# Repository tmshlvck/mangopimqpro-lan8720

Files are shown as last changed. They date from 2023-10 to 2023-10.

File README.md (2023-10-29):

LAN8720 board for MangoPi MQ-Pro
================================

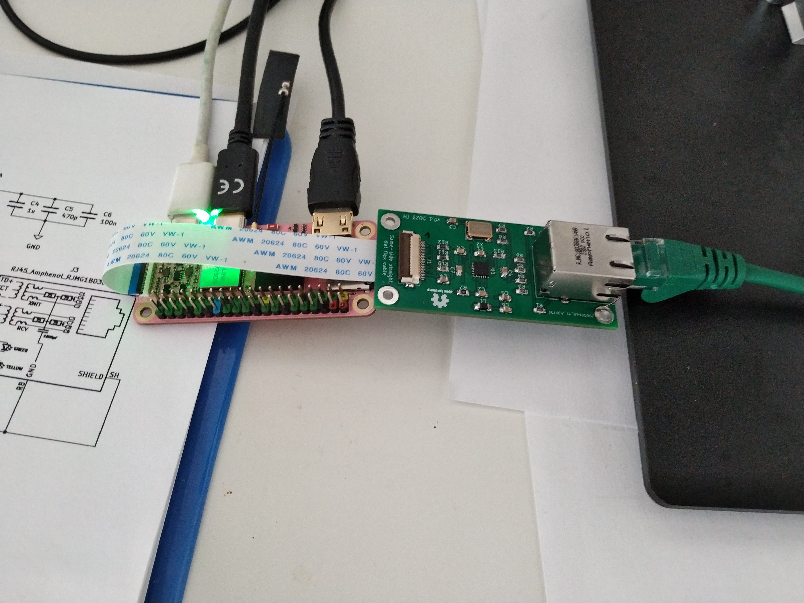
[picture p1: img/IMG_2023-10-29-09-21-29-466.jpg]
Board picture


The schematic and PCB are in HW section. Feel free to make it, it is quite cool add-on board.
Schematic: [PDF](hw/meta/schematic.pdf)

I run it with the Nezha Ubuntu image with the patch applied using this:

* clone Linux kernel tree (`git clone https://github.com/torvalds/linux.git`)
* apply the patch from this repo (`git am 0001-Add-LAN8720a-PHY-to-MangoPI-MQ-Pro-board.patch`)
* build DTB `ARCH=riscv make dtbs`
* scp the result `arch/riscv/boot/dts/allwinner/sun20i-d1-mangopi-mq-pro-lan8720.dtb` to `/boot` on MangoPi MQ-Pro
* link the current kernel DTB to this file (in my case `cd boot; rm dtb-6.2.0-35-generic; ln -s sun20i-d1-mangopi-mq-pro-lan8720.dtb dtb-6.2.0-35-generic`)
* reboot the MangoPi MQ-Pro

License
-------

HW: The TAPR Open Hardware License Version 1.0
SW: GNU GPLv3

Expected dmesg output
---------------------

```
[  104.125393] dwmac-sun8i 4500000.ethernet: IRQ eth_wake_irq not found
[  104.125445] dwmac-sun8i 4500000.ethernet: IRQ eth_lpi not found
[  104.126653] dwmac-sun8i 4500000.ethernet: PTP uses main clock
[  104.126754] dwmac-sun8i 4500000.ethernet: Current syscon value is not the default 50006 (expect 0)
[  104.140716] dwmac-sun8i 4500000.ethernet: No HW DMA feature register supported
[  104.140764] dwmac-sun8i 4500000.ethernet: RX Checksum Offload Engine supported
[  104.140794] dwmac-sun8i 4500000.ethernet: COE Type 2
[  104.140826] dwmac-sun8i 4500000.ethernet: TX Checksum insertion supported
[  104.140857] dwmac-sun8i 4500000.ethernet: Normal descriptors
[  104.140885] dwmac-sun8i 4500000.ethernet: Chain mode enabled
[  108.505636] dwmac-sun8i 4500000.ethernet end0: renamed from eth0
[  111.253079] dwmac-sun8i 4500000.ethernet end0: PHY [stmmac-0:01] driver [SMSC LAN8710/LAN8720] (irq=POLL)
[  111.260378] dwmac-sun8i 4500000.ethernet end0: Register MEM_TYPE_PAGE_POOL RxQ-0
[  111.264987] dwmac-sun8i 4500000.ethernet end0: No Safety Features support found
[  111.265046] dwmac-sun8i 4500000.ethernet end0: No MAC Management Counters available
[  111.265085] dwmac-sun8i 4500000.ethernet end0: PTP not supported by HW
[  111.282125] dwmac-sun8i 4500000.ethernet end0: configuring for phy/rmii link mode
[  287.401778] dwmac-sun8i 4500000.ethernet end0: Link is Up - 100Mbps/Full - flow control rx/tx
```

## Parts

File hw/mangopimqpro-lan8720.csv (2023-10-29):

Source: | /home/th/wip/mangopimqpro-lan8720/hw/mangopimqpro-lan8720.kicad_sch
Date: | Mon 31 Jul 2023 01:39:57 PM CEST
Tool: | Eeschema 7.0.6-1.fc38
Generator: | /usr/share/kicad/plugins/bom_csv_grouped_by_value.py
Component Count: | 28
Collated Components:
Item | Qty | Reference(s) | Value | LibPart | Footprint | Datasheet | DNP | PN
1 | 6 | C1, C2, C3, C6, C7, C8 | 100n | Device:C | Capacitor_SMD:C_0805_2012Metric_Pad1.18x1.45mm_HandSolder | ~ |  | CL21B104MACNNNC
2 | 2 | C4, C9 | 1u | Device:C | Capacitor_SMD:C_0805_2012Metric_Pad1.18x1.45mm_HandSolder | ~ |  | CL21B105KOFNNNG
3 | 1 | C5 | 470p | Device:C | Capacitor_SMD:C_0805_2012Metric_Pad1.18x1.45mm_HandSolder | ~ |  | CL21B471KBANFNC
4 | 2 | J1, J2 | Conn_01x25_Socket | Connector:Conn_01x25_Socket | Connector_FFC-FPC:Hirose_FH12-24S-0.5SH_1x24-1MP_P0.50mm_Horizontal | ~ |  | FH12-24S-0.5SH(55)
5 | 1 | J3 | RJ45_Amphenol_RJMG1BD3B8K1ANR | Connector:RJ45_Amphenol_RJMG1BD3B8K1ANR | Connector_RJ:RJ45_Amphenol_RJMG1BD3B8K1ANR | https://www.amphenol-cs.com/media/wysiwyg/files/drawing/rjmg1bd3b8k1anr.pdf |  | RJMG1BD3B8K1ANR
6 | 1 | L1 | 1uH | Device:L | Inductor_SMD:L_1206_3216Metric_Pad1.22x1.90mm_HandSolder | ~ |  | MCQ1V3216-1R0-R
7 | 2 | R1, R2 | 330 | Device:R | Resistor_SMD:R_0805_2012Metric_Pad1.20x1.40mm_HandSolder | ~ |  | RMCF0805JT330R
8 | 7 | R3, R4, R5, R6, R8, R9, R10 | 50 | Device:R | Resistor_SMD:R_0805_2012Metric_Pad1.20x1.40mm_HandSolder | ~ |  | RMCF0805JT51R0
9 | 3 | R7, R11, R12 | 5k | Device:R | Resistor_SMD:R_0805_2012Metric_Pad1.20x1.40mm_HandSolder | ~ |  | CRCW08055K00JNTA
10 | 1 | R13 | 12k1 | Device:R | Resistor_SMD:R_0805_2012Metric_Pad1.20x1.40mm_HandSolder | ~ |  | RMCF0805FG12K1
11 | 1 | U1 | LAN8720A | Interface_Ethernet:LAN8720A | Package_DFN_QFN:VQFN-24-1EP_4x4mm_P0.5mm_EP2.5x2.5mm_ThermalVias | http://ww1.microchip.com/downloads/en/DeviceDoc/8720a.pdf |  | LAN8720A-CP-ABC
12 | 1 | X2 | SG-7050CAN | Oscillator:SG-7050CAN | Oscillator:Oscillator_SMD_SeikoEpson_SG8002CA-4Pin_7.0x5.0mm | https://support.epson.biz/td/api/doc_check.php?dl=brief_SG7050CAN&lang=en |  | SG7050CAN 50.000000M-TJGA0

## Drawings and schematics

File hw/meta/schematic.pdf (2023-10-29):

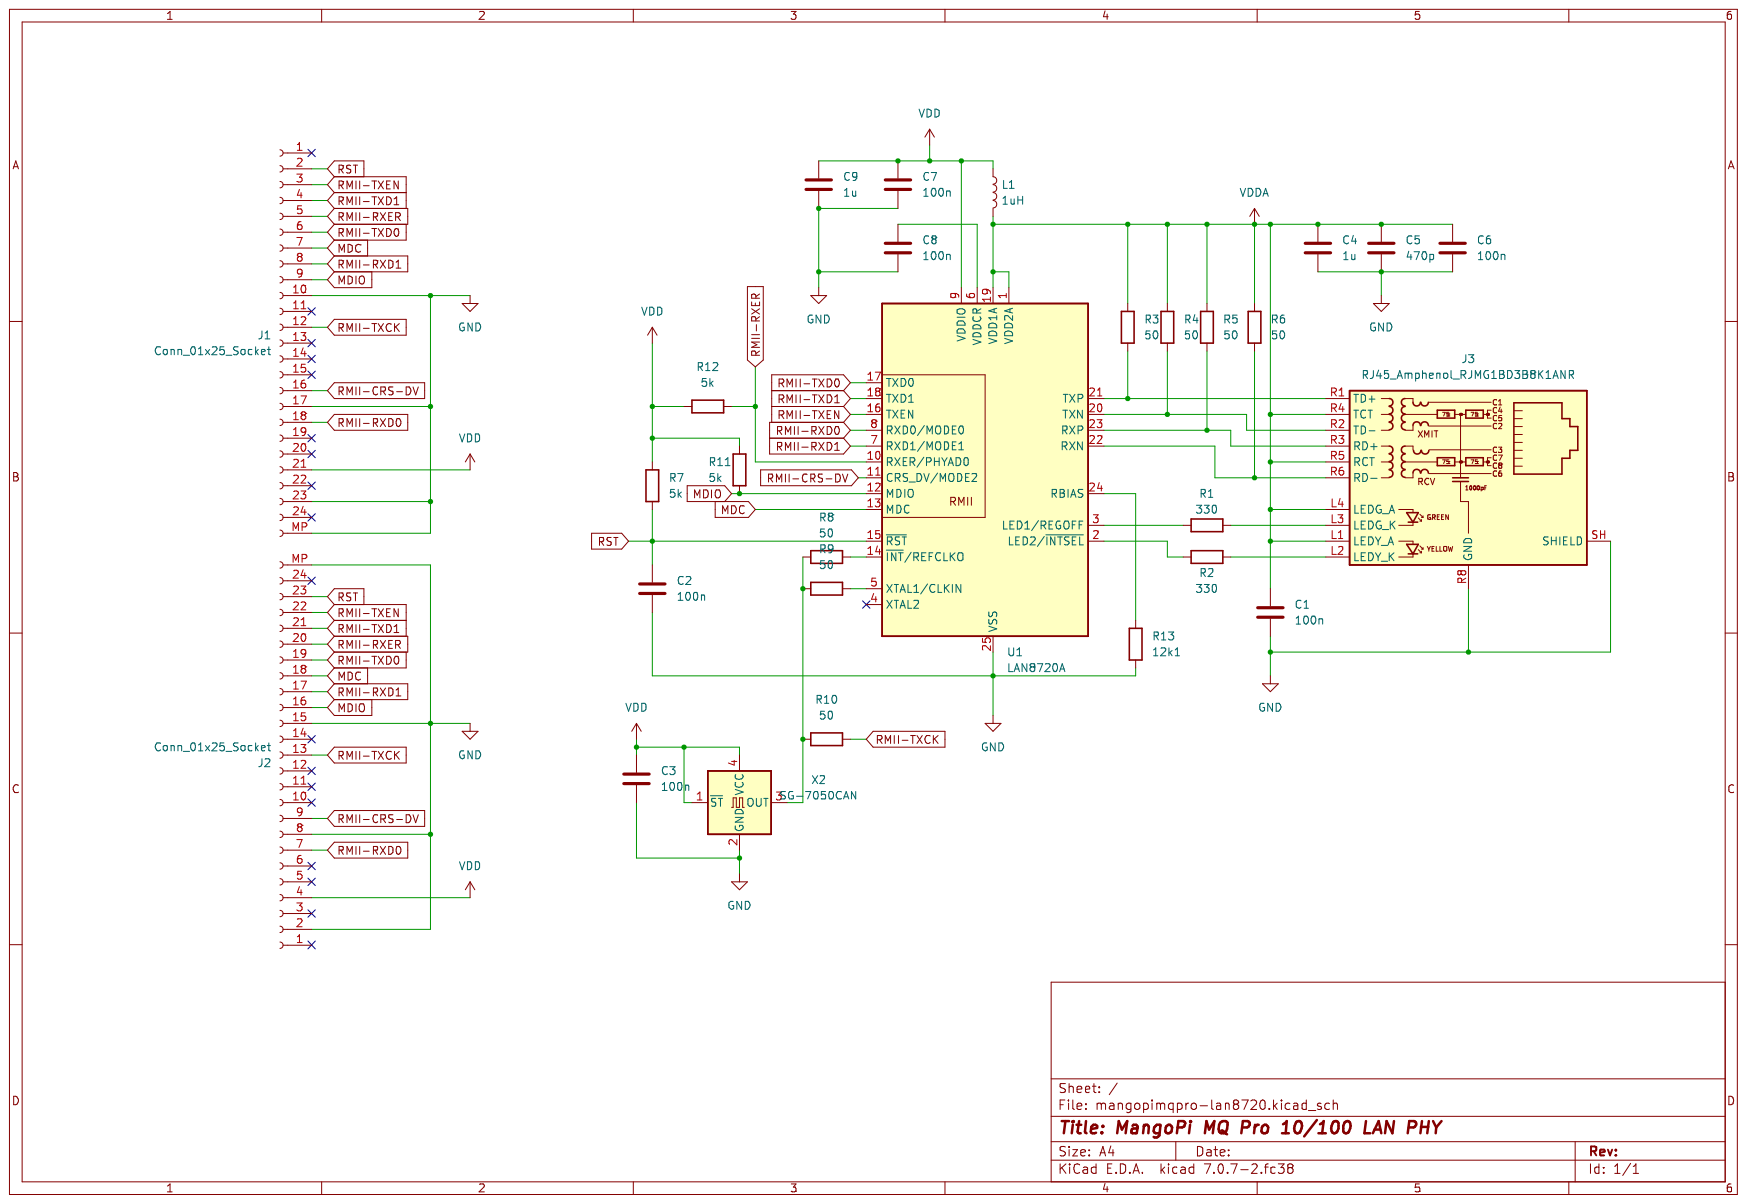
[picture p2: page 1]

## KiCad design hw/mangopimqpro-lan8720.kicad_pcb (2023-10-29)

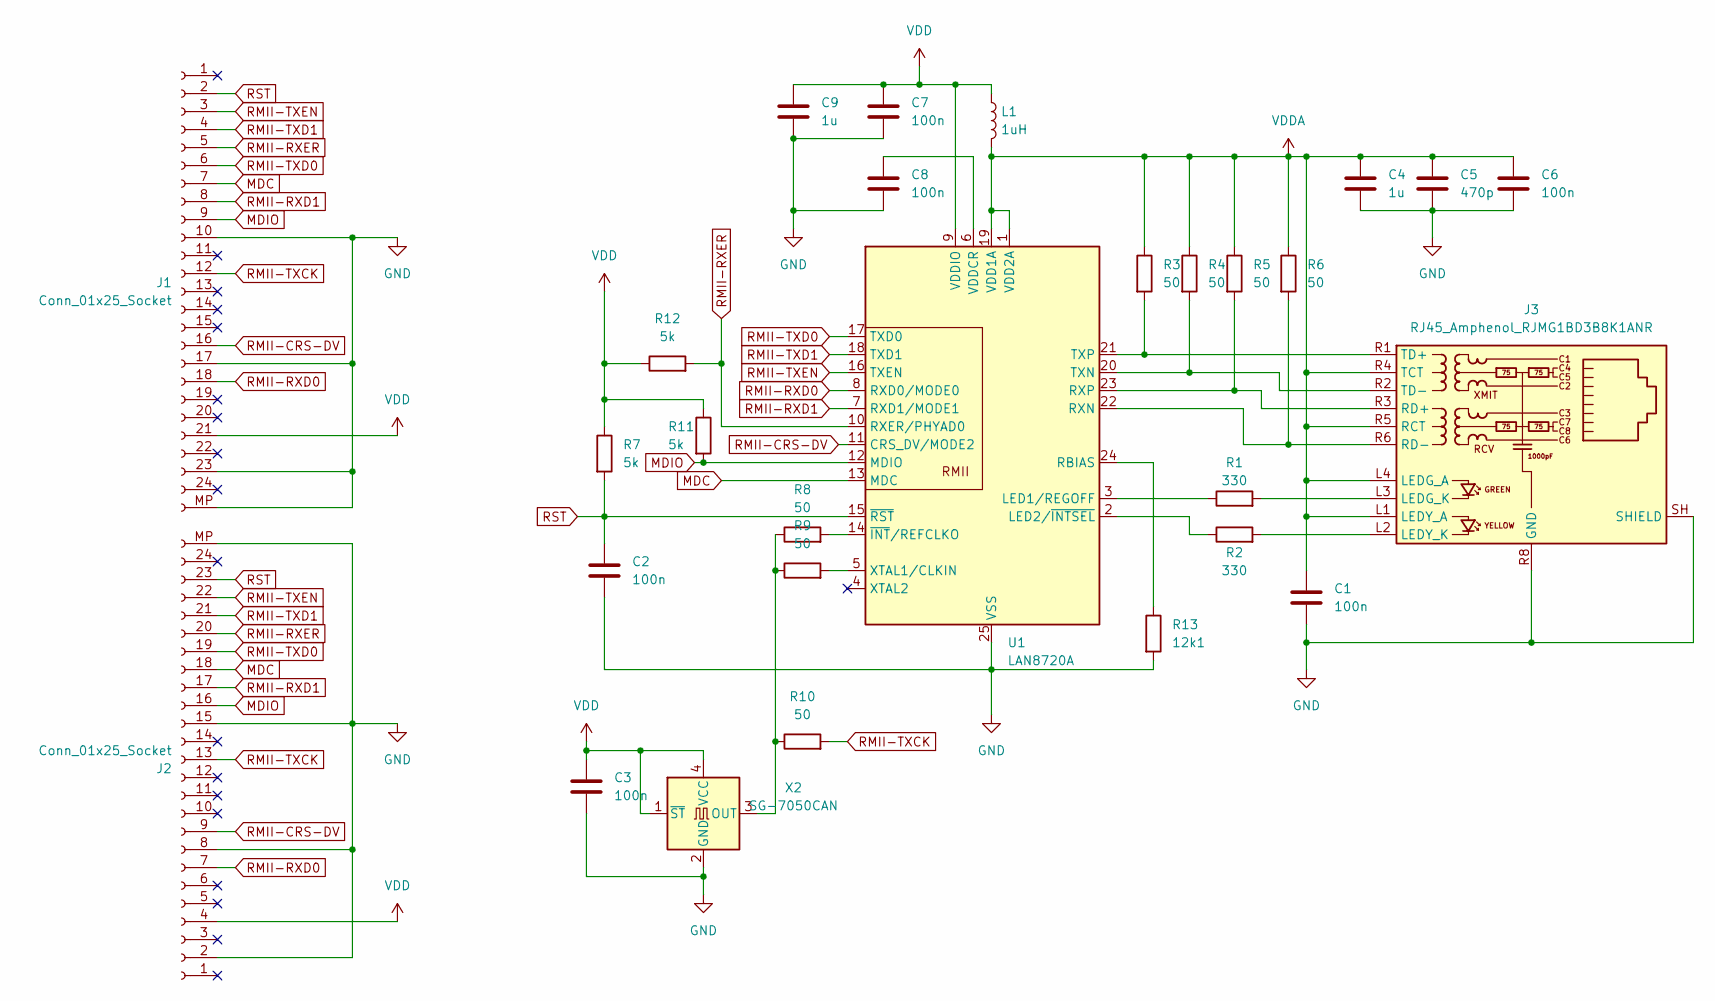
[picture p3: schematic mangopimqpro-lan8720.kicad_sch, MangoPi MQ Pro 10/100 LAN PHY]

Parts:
C1, C2, C3, C6, C7, C8: 100n; C_0805_2012Metric_Pad1.18x1.45mm_HandSolder
C4, C9: 1u; C_0805_2012Metric_Pad1.18x1.45mm_HandSolder
C5: 470p; C_0805_2012Metric_Pad1.18x1.45mm_HandSolder
J1, J2: Conn_01x25_Socket; Hirose_FH12-24S-0.5SH_1x24-1MP_P0.50mm_Horizontal
J3: RJ45_Amphenol_RJMG1BD3B8K1ANR
L1: 1uH; L_1206_3216Metric_Pad1.22x1.90mm_HandSolder
R1, R2: 330; R_0805_2012Metric_Pad1.20x1.40mm_HandSolder
R3, R4, R5, R6, R8, R9, R10: 50; R_0805_2012Metric_Pad1.20x1.40mm_HandSolder
R7, R11, R12: 5k; R_0805_2012Metric_Pad1.20x1.40mm_HandSolder
R13: 12k1; R_0805_2012Metric_Pad1.20x1.40mm_HandSolder
U1: LAN8720A; VQFN-24-1EP_4x4mm_P0.5mm_EP2.5x2.5mm_ThermalVias
X2: SG-7050CAN; Oscillator_SMD_SeikoEpson_SG8002CA-4Pin_7.0x5.0mm

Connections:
GND: C1.2, C2.2, C3.2, C4.2, C5.2, C6.2, C7.2, C8.2, C9.2, J1.10, J1.17, J1.23, J1.MP (Pin_25), J2.2, J2.8, J2.15, J2.MP (Pin_25), J3.R8 (GND), J3.SH (SHIELD), R13.2, U1.25 (VSS), X2.2 (GND)
MDC: J1.7, J2.18, U1.13 (MDC)
MDIO: J1.9, J2.16, R11.2, U1.12 (MDIO)
unnamed: J3.L3 (LEDG_K), R1.2
unnamed: J3.L2 (LEDY_K), R2.2
unnamed: J3.R3 (RD+), R5.2, U1.23 (RXP)
unnamed: J3.R6 (RD-), R6.2, U1.22 (RXN)
unnamed: J3.R1 (TD+), R3.2, U1.21 (TXP)
unnamed: J3.R2 (TD-), R4.2, U1.20 (TXN)
unnamed: R1.1, U1.3 (LED1/REGOFF)
unnamed: R2.1, U1.2 (LED2/~INTSEL)
unnamed: R13.1, U1.24 (RBIAS)
unnamed: C8.1, U1.6 (VDDCR)
unnamed: R9.2, U1.5 (XTAL1/CLKIN)
unnamed: R8.2, U1.14 (~INT/REFCLKO)
unnamed: R8.1, R9.1, R10.1, X2.3 (OUT)
RMII-CRS-DV: J1.16, J2.9, U1.11 (CRS_DV/MODE2)
RMII-RXD0: J1.18, J2.7, U1.8 (RXD0/MODE0)
RMII-RXD1: J1.8, J2.17, U1.7 (RXD1/MODE1)
RMII-RXER: J1.5, J2.20, R12.2, U1.10 (RXER/PHYAD0)
RMII-TXCK: J1.12, J2.13, R10.2
RMII-TXD0: J1.6, J2.19, U1.17 (TXD0)
RMII-TXD1: J1.4, J2.21, U1.18 (TXD1)
RMII-TXEN: J1.3, J2.22, U1.16 (TXEN)
RST: C2.1, J1.2, J2.23, R7.2, U1.15 (~RST)
VDD: C3.1, C7.1, C9.1, J1.21, J2.4, L1.1, R7.1, R11.1, R12.1, U1.9 (VDDIO), X2.1 (~ST), X2.4 (VCC)
VDDA: C1.1, C4.1, C5.1, C6.1, J3.L1 (LEDY_A), J3.L4 (LEDG_A), J3.R4 (TCT), J3.R5 (RCT), L1.2, R3.1, R4.1, R5.1, R6.1, U1.1 (VDD2A), U1.19 (VDD1A)

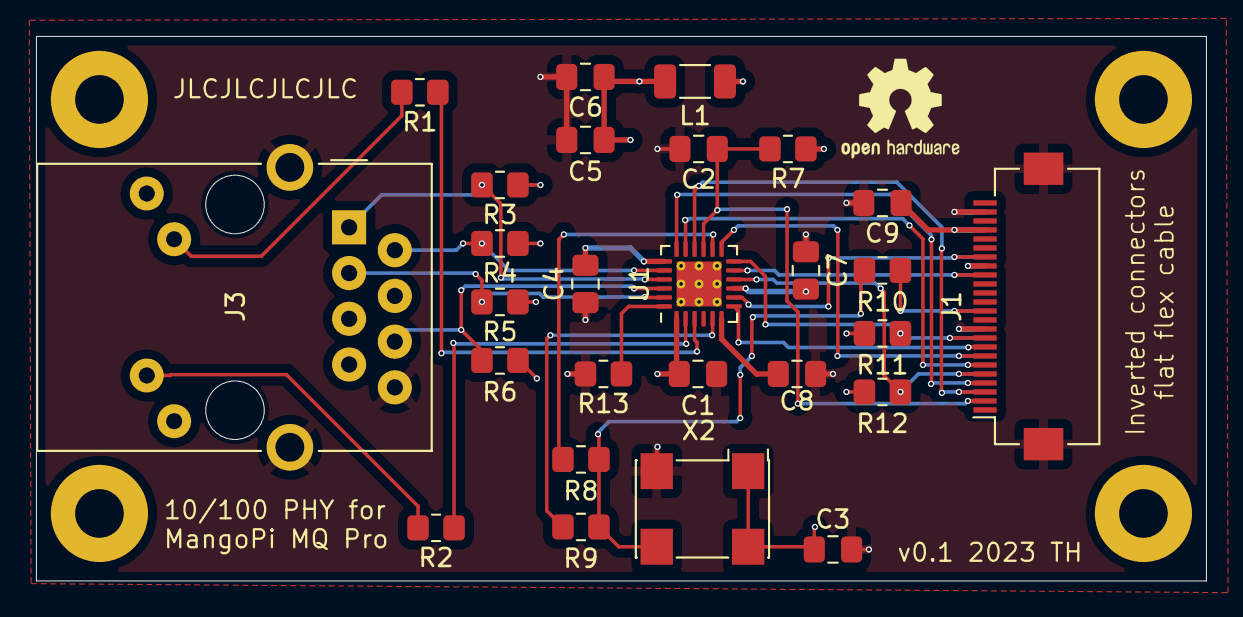
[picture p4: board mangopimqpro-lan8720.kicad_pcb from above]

Board: 4 copper layers, 65.0 x 30.2 mm, 28 parts (1 on the bottom side), 27 nets.

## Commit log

2023-07-16 Inital commit
    Add basic README, pinout connections table and testing patch for Linux
    kernel to enable the breadboard experimental version of the future
    circuit.
2023-10-29 Add v0.1 board
    Add v0.1 board - schematic + PCB drawing + fabrication outputs
    Add new patch for MangoPi MQ-Pro
    Add patch application guide to README
    Add licenses for the artifacts
    [mangopimqpro-lan8720-B_Cu.gbr, mangopimqpro-lan8720-B_Mask.gbr, mangopimqpro-lan8720-B_Paste.gbr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]
2023-10-29 Add board picture and links to README
2025-03-25 Fix typo in 0001-Add-LAN8720a-PHY-to-MangoPI-MQ-Pro-board.patch
    Fix typo in Makefile modification in 0001-Add-LAN8720a-PHY-to-MangoPI-MQ-Pro-board.patch
